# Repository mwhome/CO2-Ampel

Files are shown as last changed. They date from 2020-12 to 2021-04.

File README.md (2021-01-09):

# CO2-Ampel
Eine CO2 Ampel mit esp8266, ccs811 Sensor, beliebig vielen WS2812 LEDs und OLED Display 128x32

Im Code die Anzahl der WS2812 LEDs anpassen, sollte kein DHT-Sensor verwendet werden die entsprechende Zeile "#define DHTSENSOR" auskommentieren.
Nach dem erstmaligen Einschalten sich mit dem Accesspoint "CO2 Ampel" und dem Passwort "12345678" verbinden und das eigene Wifi auswählen.
Nach kurzem Aufleuchten aller LEDs in grün wird die IP-Adresse durch die LEDs ausgegeben.
Die 17. LED blinkt entsprechend, blau bedeutet nächste Zahl, rot bedeutet Punkt (also 192.168.0.25 wäre also 1 mal grün, blau, 9mal grün, blau, 2mal grün, blau, rot, 1mal grün, blau 6mal grün, blau, 8mal grün, blau, rot, blau, blau, blau, rot, blau, 2mal grün,blau, 5mal grün, blau, rot)

Verdrahtung:
Data des WS2812 auf D8 des ESP
VCC (WS2812) auf 5V (ESP)
SDA (CCS811) auf D2 des ESP
SDL (CCS811) auf D1 des ESP
WAK (CCS811) auf GND !!!!!
VCC (CSS811) auf 3,3V(ESP)
GND ....

Benötigte libraries:

- unter “Datei”, “Voreinstellungen” folgende zusätzliche Boardverwalter-URL hinzufügen: http://arduino.esp8266.com/stable/package_esp8266com_index.json
- unter "Werkzeuge" >> "Board" >> "Boardverwalter" >>"ESP8266 Boards" den WeMos D1 R1 auswählen
- Sparkfun CCS811 Arduino Library  ("Werkzeuge" >> "Bibliotheken verwalten" nach Sparkfun CCS811 suchen und installieren)
- Adafruit NeoPixel by Adafruit ("Werkzeuge" >> "Bibliotheken verwalten" nach Adafruit Neopixel suchen und installieren)
- Adafruit SSD1306  ("Werkzeuge" >> "Bibliotheken verwalten" nach Adafruit SSD1306 suchen und installieren)

Das Gehäuse mit den Buchstaben CO2 findet man hier:

https://www.tinkercad.com/things/ipEyfYHhAQ5

https://www.tinkercad.com/things/5hAtBOBWlKD

Die Buchstaben mit transparentem Filament und 3% Füllung drucken, damit sie durchscheinend sind und die Beleuchtung von unten gut gelingt. Die drei LEDs unter den Buchstaben werden nur als eine LED angesteuert (im Code eine WS2812b LED angeben), alle drei Datenleitungen der LEDs werden mit D8 am WEMOS verbunden.

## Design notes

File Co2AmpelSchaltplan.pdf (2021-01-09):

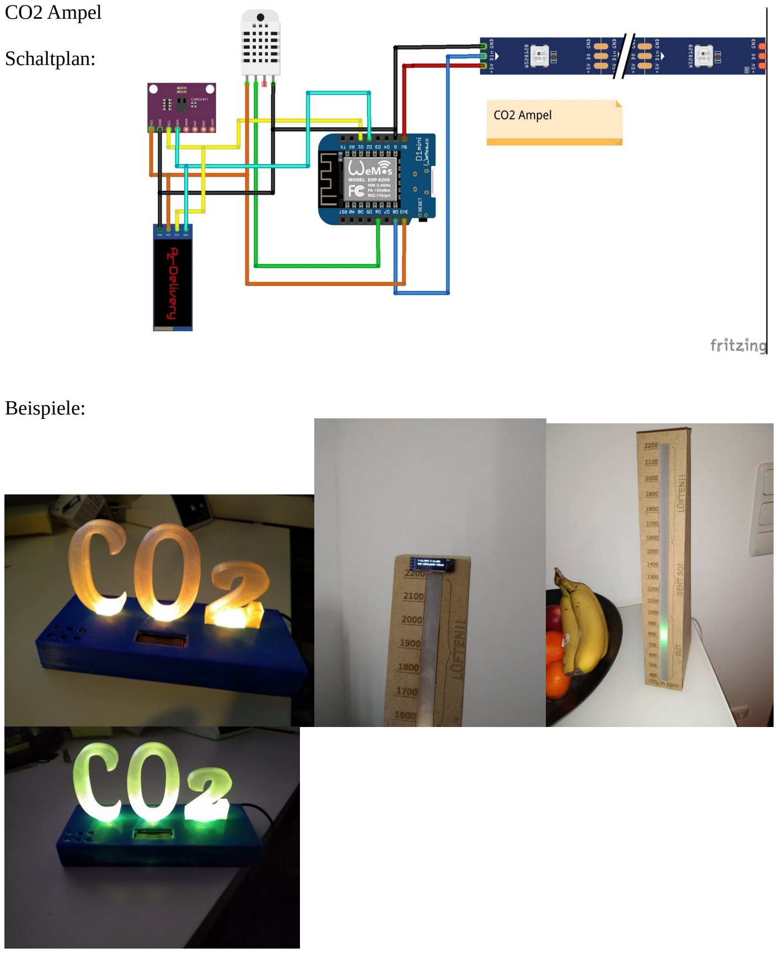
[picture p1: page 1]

CO2 Ampel

Schaltplan:

Beispiele:

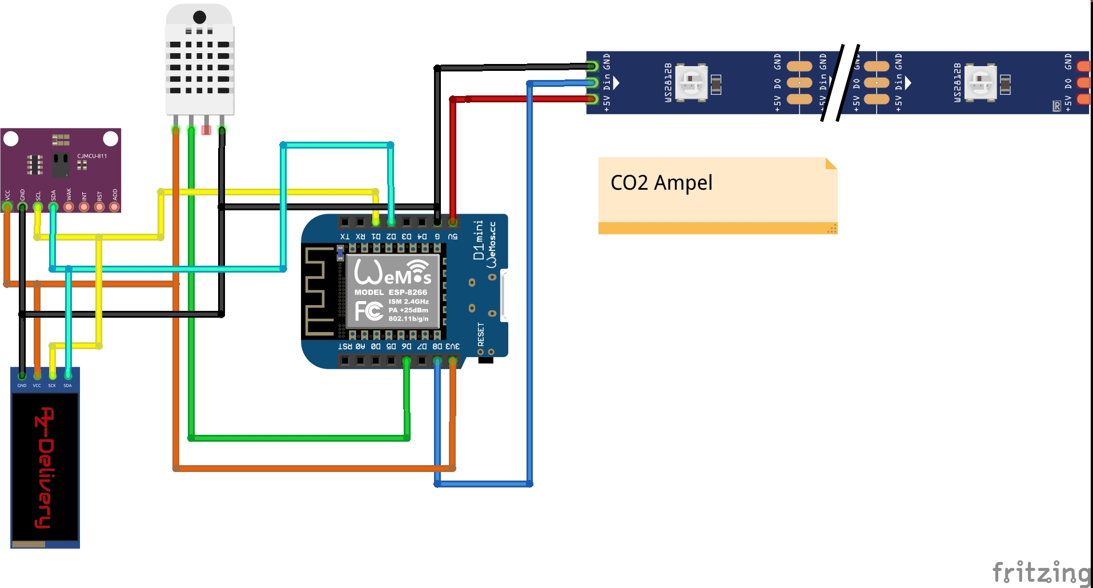
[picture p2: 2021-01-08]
SchaltplanCO2Ampel.jpg

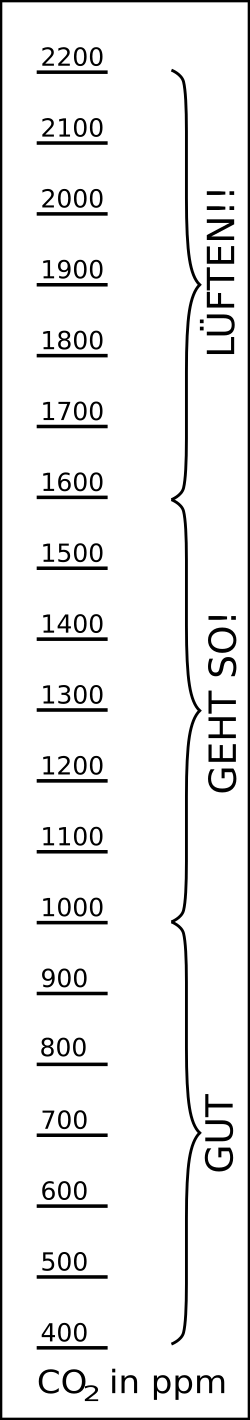
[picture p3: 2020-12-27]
front.png

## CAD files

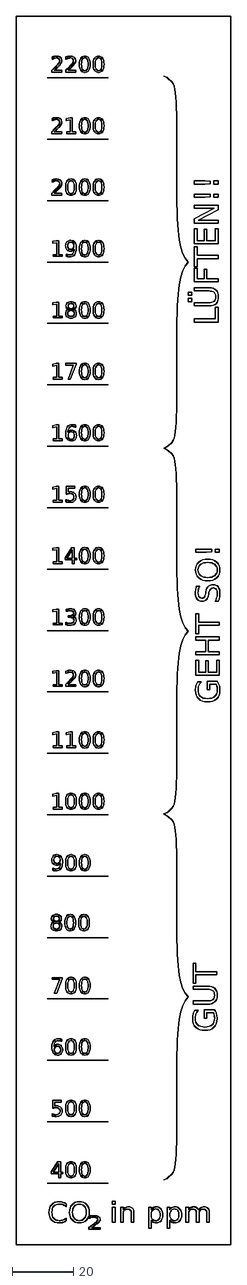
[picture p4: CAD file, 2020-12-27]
Front.dxf
69.8 x 400.1

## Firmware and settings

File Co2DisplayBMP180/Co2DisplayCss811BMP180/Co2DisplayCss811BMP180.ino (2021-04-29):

/*********
CO2 Luftqualität mit Arduino Nano, ccs811, ws2812, BMP180  und OLED Display 128*32
*********/
//Anschluss am Arduino Nano
//SDA an A4, SCL an A5, Vcc an 3,3V und GND an GND
//WS2812 an 5V (Vin), GND und Data an A1
//
#include "SparkFunCCS811.h" 
#include <SPI.h>
#include <Wire.h>
#include <Adafruit_NeoPixel.h>
#include <Adafruit_GFX.h>
#include <Adafruit_SSD1306.h>
#include <Adafruit_Sensor.h>
#include <Adafruit_Sensor.h>
#include <Adafruit_BMP085_U.h>


#define CCS811_ADDR 0x5A //Alternative I2C Addresse des CCS811 Sensors
#define NUM_PIXEL 19    //Anzahl der WS2812 LEDs
#define PIN 15          // Data Anschluss des WS2812 Wemos D8
Adafruit_NeoPixel strip = Adafruit_NeoPixel(NUM_PIXEL, PIN, NEO_GRB + NEO_KHZ800);
CCS811 mySensor(CCS811_ADDR);     //CCS811 Sensorlibrary von Sparkfun
#define SCREEN_WIDTH 128 // OLED display width, in pixels
#define SCREEN_HEIGHT 32 // OLED display height, in pixels


Adafruit_SSD1306 display(SCREEN_WIDTH, SCREEN_HEIGHT, &Wire);
Adafruit_BMP085_Unified bmp = Adafruit_BMP085_Unified(10085);

float TEMP = 0;

int P = NUM_PIXEL/2;
unsigned int CO2 = 400;
unsigned int TVOC = 0;

// Current time
unsigned long currentTime = millis();
// Previous time
unsigned long previousTime = 0; 
// Define timeout time in milliseconds (example: 2000ms = 2s)
const long timeoutTime = 2000;



void setup() {
 Serial.begin(115200);
    Wire.begin();
    //bmp.begin();
 
   strip.begin();
  clearStrip();
  strip.show();
  strip.setBrightness(200);
  
  //Serial.println("Pressure Sensor Test"); Serial.println("");
  
  /* Initialise the sensor */
if(!bmp.begin())
{
  /* There was a problem detecting the BMP085 ... check your connections */
  Serial.print("Ooops, no BMP085 detected ... Check your wiring or I2C ADDR!");
  while(1);
}
  
  /* Display some basic information on this sensor */
  displaySensorDetails();


  // SSD1306_SWITCHCAPVCC = generate display voltage from 3.3V internally
  if(!display.begin(SSD1306_SWITCHCAPVCC, 0x3C)) { // Address 0x3C for 128x32
    Serial.println(F("SSD1306 allocation failed"));
    for(;;); // Don't proceed, loop forever
  }

if (mySensor.begin() == false)
  {
    Serial.print("CCS811 error. Please check wiring. Freezing...");
    while (1)
      ;
  }


  // Clear the buffer
  display.clearDisplay();

  // text display tests
  display.setTextSize(2);
  display.setTextColor(WHITE);
  display.setCursor(0,0);
    display.print(F("CO"));
    display.setTextSize(1);
    display.setCursor(23,10);
    display.print(F("2"));
    display.setTextSize(2);
    display.setCursor(28,0);
  display.println("-Ampel");
  display.setTextSize(1);
    display.setCursor(0,20);
  display.println("Markus Weber");
  display.display();
  delay(4000);
  
  display.clearDisplay();
  
}
 
void loop() {
   //Check to see if data is ready with .dataAvailable()
  if (mySensor.dataAvailable())
  {
    //If so, have the sensor read and calculate the results.
    //Get them later
    mySensor.readAlgorithmResults();

    Serial.print("CO2: ");
    //Returns calculated CO2 reading
    Serial.print(mySensor.getCO2());
    Serial.print(" ppm  tVOC: ");
    //Returns calculated TVOC reading
    Serial.print(mySensor.getTVOC());
     Serial.print(" ppb");
    
    Serial.println();
  }

  delay(10); //Don't spam the I2C bus

sensors_event_t event;
  bmp.getEvent(&event);
 
  /* Display the results (barometric pressure is measure in hPa) */
  if (event.pressure)
  {
    /* Display atmospheric pressue in hPa */
    Serial.print("Pressure:    ");
    Serial.print(event.pressure);
    Serial.println(" hPa");
    
    /* Calculating altitude with reasonable accuracy requires pressure    *
     * sea level pressure for your position at the moment the data is     *
     * converted, as well as the ambient temperature in degress           *
     * celcius.  If you don't have these values, a 'generic' value of     *
     * 1013.25 hPa can be used (defined as SENSORS_PRESSURE_SEALEVELHPA   *
     * in sensors.h), but this isn't ideal and will give variable         *
     * results from one day to the next.                                  *
     *                                                                    *
     * You can usually find the current SLP value by looking at weather   *
     * websites or from environmental information centers near any major  *
     * airport.                                                           *
     *                                                                    *
     * For example, for Paris, France you can check the current mean      *
     * pressure and sea level at: http://bit.ly/16Au8ol                   */
     
    /* First we get the current temperature from the BMP085 */
    float temperature;
    bmp.getTemperature(&temperature);
    Serial.print("Temperatur: ");
    Serial.print(temperature-4);
    TEMP = temperature-4;
    Serial.println(" C");
    Serial.println("");
  }
  else
  {
    Serial.println("Sensor error");
  }


CO2 = mySensor.getCO2();
TVOC = mySensor.getTVOC();

  if ((CO2) < 2100) {
    { int t = map(CO2, 400, 2100, 1, NUM_PIXEL);int f = map(CO2, 400, 2100, 0, 255);
       
        clearStrip();
        strip.setPixelColor((t-1),f,255-f,0); 
     
      
      strip.show(); //Output on strip
 
  display.clearDisplay();
  display.setTextSize(2);
    display.setCursor(0,0);
    display.print(F("CO"));
    display.setTextSize(1);
    display.setCursor(23,10);
    display.print(F("2"));
    display.setTextSize(2);
    display.setCursor(28,0);
    display.print(F(":"));
    display.print(mySensor.getCO2());
    display.setCursor(50,20);
    display.setTextSize(1);
    display.println(F("ppm"));

     // text display 

  display.display();
    delay(2000);
  
  display.clearDisplay();
    display.setTextSize(1);
    display.setCursor(0,20);
    display.print(F("tVOC:"));
    display.print(mySensor.getTVOC());
    display.println(F("ppb"));
      display.setCursor(60,20);
    display.print(F(":"));
    display.print(event.pressure);
    display.println(F("hPa"));
    display.setCursor(0,0);
    display.setTextSize(2);
    display.print(TEMP);
    display.print((char)247);
    display.print(F("C"));
  
  // text display 

  display.display();
    delay(2000);

      
     }
  }
  else {
    (CO2) = 2100;
        clearStrip();
        strip.setPixelColor(NUM_PIXEL-1,255,0,0); 
        strip.show(); //Output on strip
        display.clearDisplay();
    
    display.setTextSize(2);
    display.setCursor(0,0);
    display.print(F("CO"));
    display.setTextSize(1);
    display.setCursor(23,10);
    display.print(F("2"));
    display.setTextSize(2);
    display.setCursor(28,0);
    display.print(F(":"));
    display.print(mySensor.getCO2());
    display.setCursor(50,20);
    display.setTextSize(1);
    display.println(F("ppm"));
        
    display.display();
  delay(750);  
   
      clearStrip();
      strip.show(); //Output on strip
  delay(750);
     

        clearStrip();
        strip.setPixelColor(NUM_PIXEL-1,255,0,0); 
        strip.show(); //Output on strip
      
    display.clearDisplay();
    display.setTextSize(1);
    display.setCursor(15,5);
    display.print(F("FENSTER AUF !"));
    display.setCursor(15,20);
    display.print(F("Sauerstoff !"));
    display.display();
  delay(750);   
      clearStrip();
      strip.show(); //Output on strip
  delay(750);

     }

}

void clearStrip() {
  for (int i = 0; i < NUM_PIXEL; i++) {
    strip.setPixelColor(i, 0);
  }
}

void displaySensorDetails(void)
{
  sensor_t sensor;
  bmp.getSensor(&sensor);
  Serial.println("------------------------------------");
  Serial.print  ("Sensor:       "); Serial.println(sensor.name);
  Serial.print  ("Driver Ver:   "); Serial.println(sensor.version);
  Serial.print  ("Unique ID:    "); Serial.println(sensor.sensor_id);
  Serial.print  ("Max Value:    "); Serial.print(sensor.max_value); Serial.println(" hPa");
  Serial.print  ("Min Value:    "); Serial.print(sensor.min_value); Serial.println(" hPa");
  Serial.print  ("Resolution:   "); Serial.print(sensor.resolution); Serial.println(" hPa");  
  Serial.println("------------------------------------");
  Serial.println("");
  delay(500);
}
